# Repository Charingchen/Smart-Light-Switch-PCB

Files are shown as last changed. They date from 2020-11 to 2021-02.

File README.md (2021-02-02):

# Smart Light Switch PCB
This board is powered by Flyback converter, converting 120VAC to 5VDC to power the ESP32 microcontroller. The onboard temperture sensor and montion sensor would be used for smart home configrations 
## Flyback Converter Schematic
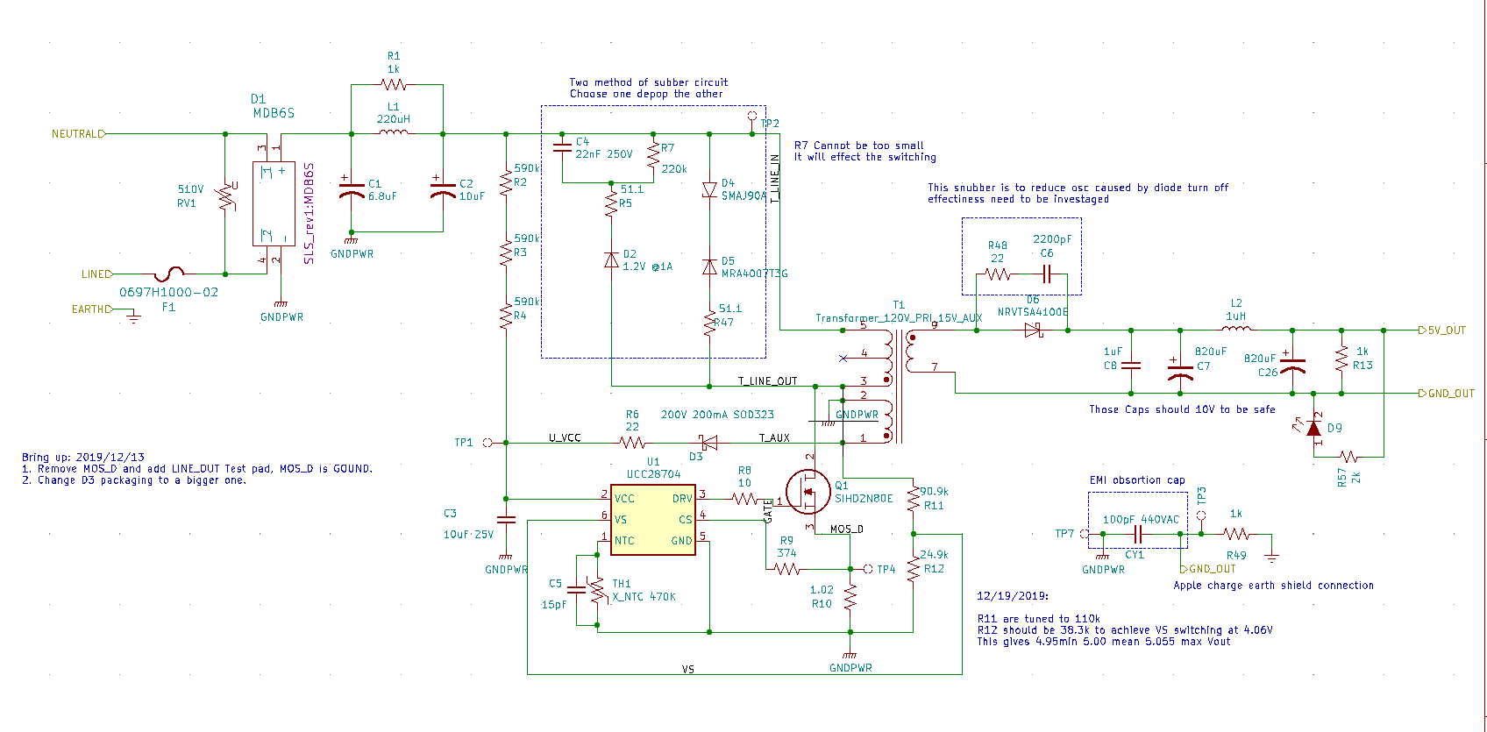
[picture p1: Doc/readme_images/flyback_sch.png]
sch

## PCB
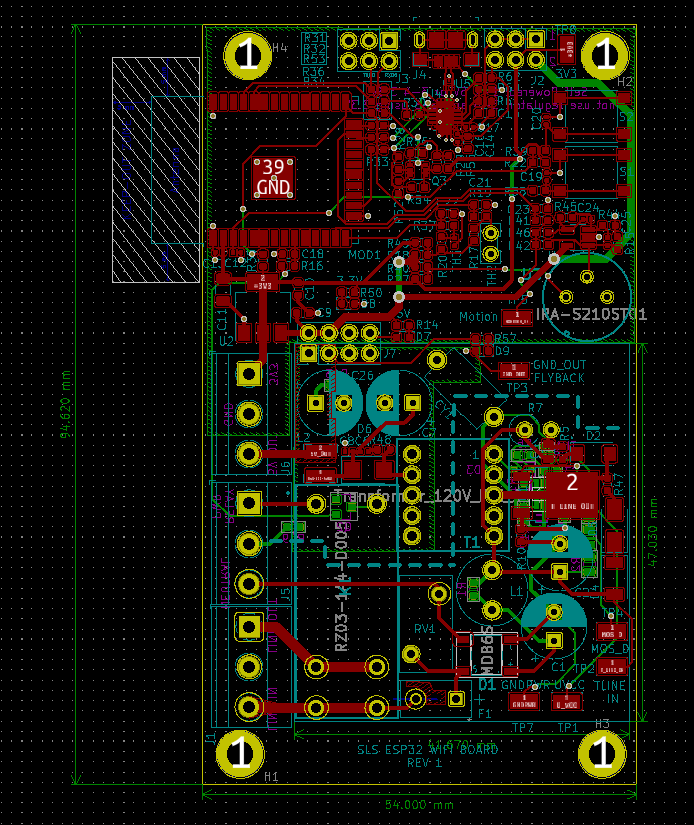
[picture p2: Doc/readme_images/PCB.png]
PCB

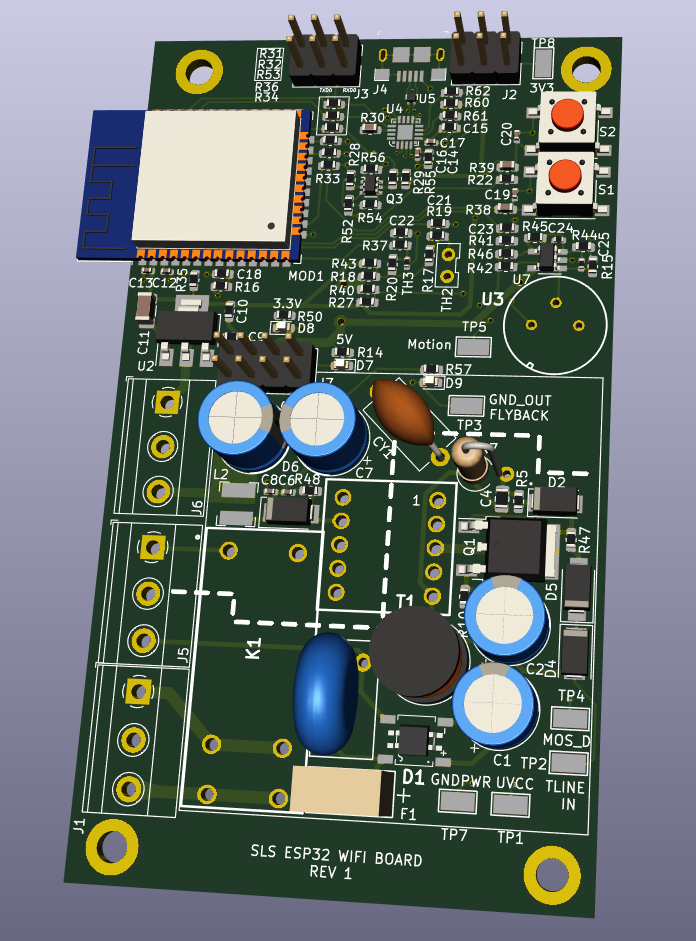
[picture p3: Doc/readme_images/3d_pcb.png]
3d


## Rev 1 Flyback Assemble PCB
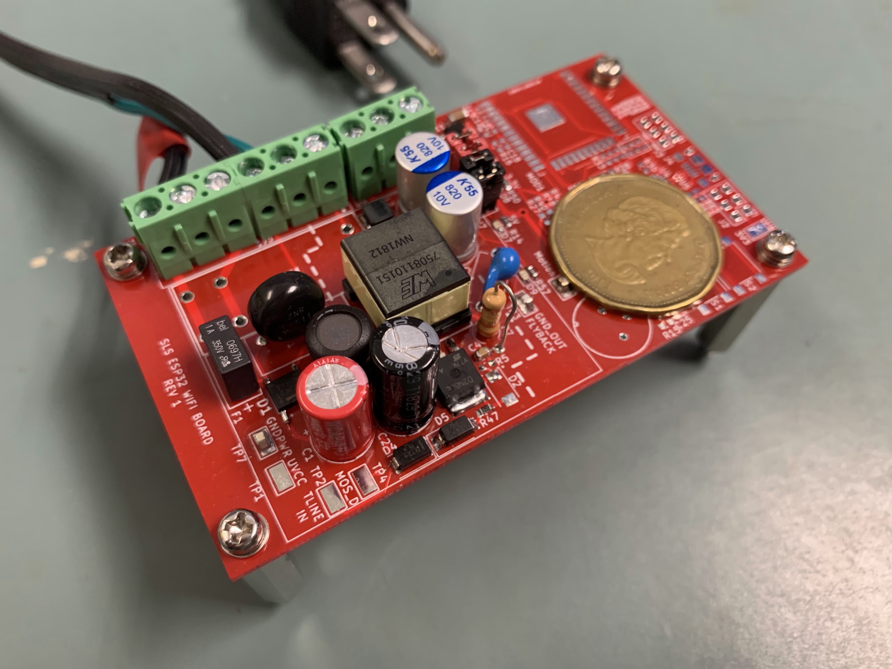
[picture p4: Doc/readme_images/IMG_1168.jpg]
product


## Kicad
This project uses Kicad to draw schematic and PCB
You can download [Kicad](https://kicad.org/) and open SLS_rev1.pro

### Digikey Library
I used digikey kicad Library to place most of the components:
https://www.digikey.ca/en/resources/design-tools/kicad

## Blog Post

I wrote some blog post talk about flyback controller, you can check them out below:

 <a target="_blank" href="https://github-readme-medium-recent-article.vercel.app/medium/@charingchen/2">Recent Article 2
 
 <a target="_blank" href="https://github-readme-medium-recent-article.vercel.app/medium/@charingchen/3">Recent Article 3

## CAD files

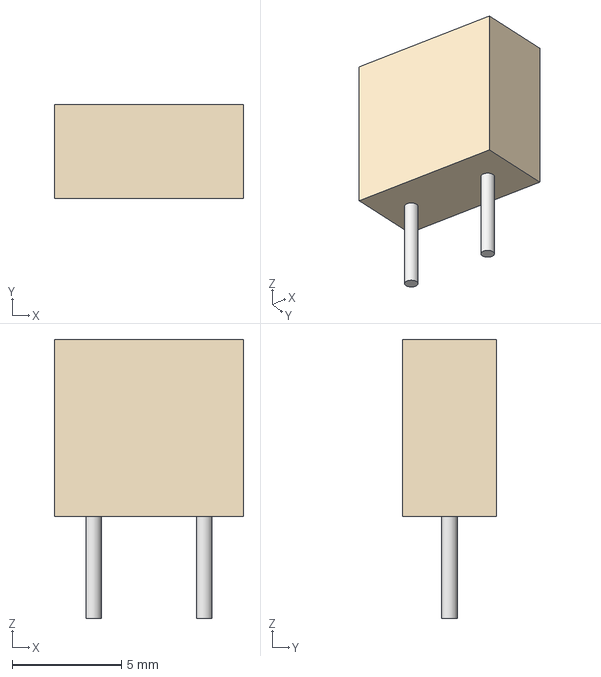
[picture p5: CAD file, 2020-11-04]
external lib/2019-09-20_19-07-09/STEP/0697.step
8.66 x 4.29 x 12.8 mm

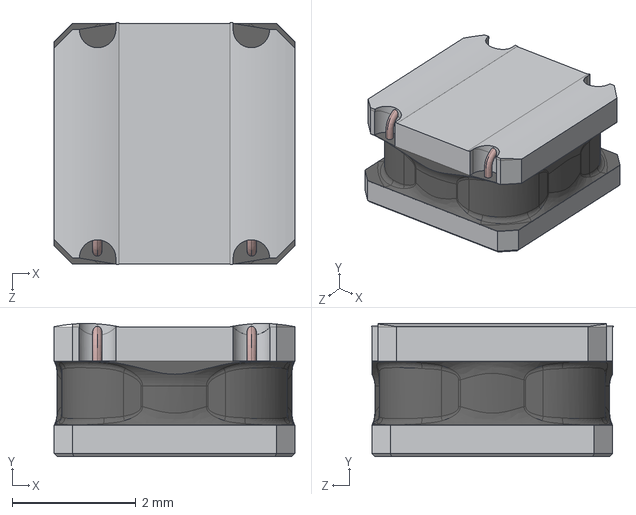
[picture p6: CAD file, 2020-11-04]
external lib/PCB footprint 3D/SRN4026 Series.stp
3.90 x 2.15 x 3.91 mm

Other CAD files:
external lib/UL_0697H100002/2019-10-03_00-56-25/STEP/0697.step

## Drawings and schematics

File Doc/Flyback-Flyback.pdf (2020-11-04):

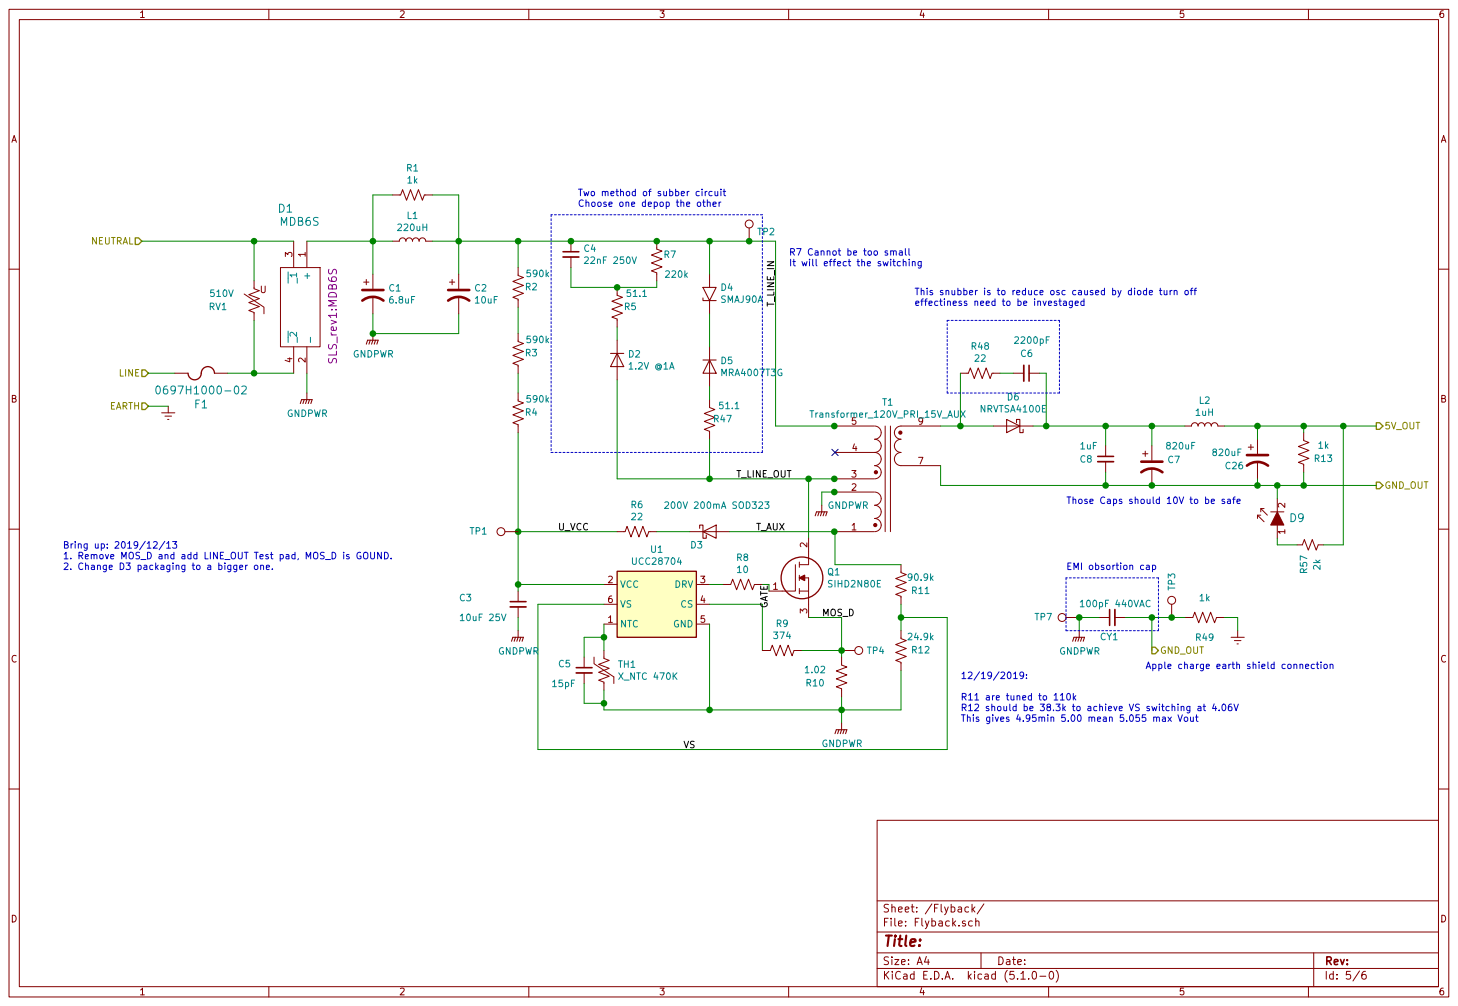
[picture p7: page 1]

Two method of subber circuit Choose one depop the other

R7 Cannot be too small It will effect the switching
51.1 D4 SMAJ90A

This snubber is to reduce osc caused by diode turn off

Those Caps should 10V to be safe

Bring up: 2019/12/13
1. Remove MOS_D and add LINE_OUT Test pad, MOS_D is GOUND.

Apple charge earth shield connection

This gives 4.95min 5.00 mean 5.055 max Vout

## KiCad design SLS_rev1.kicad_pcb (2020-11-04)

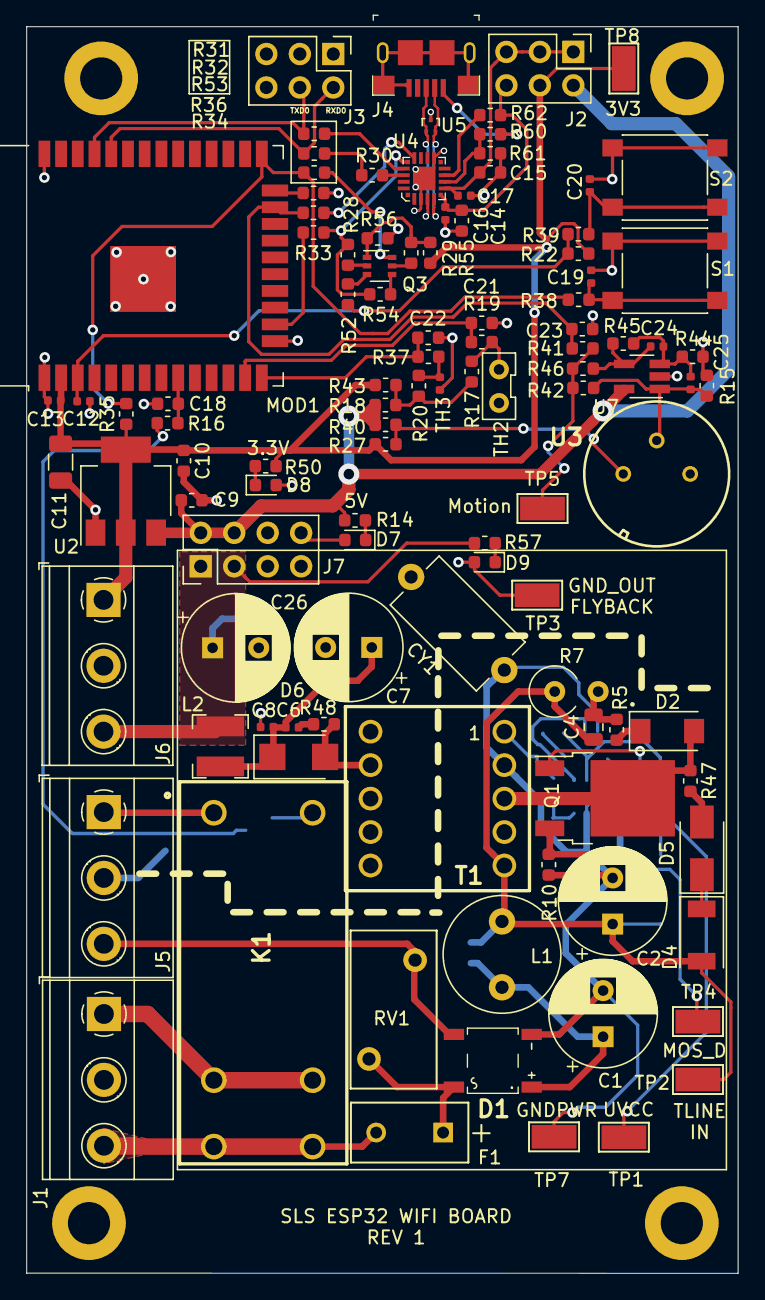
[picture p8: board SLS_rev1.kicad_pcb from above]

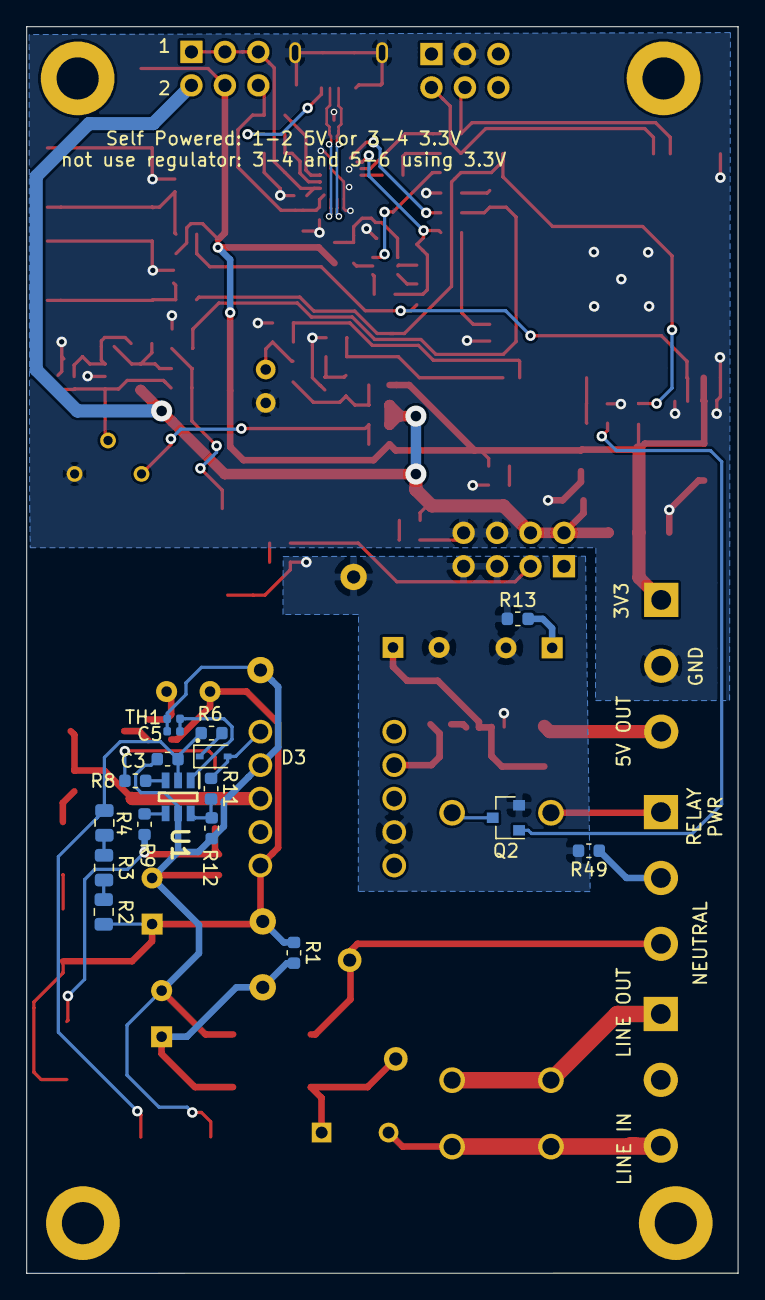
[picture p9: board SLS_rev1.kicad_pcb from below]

Board: 2 copper layers, 54.0 x 94.6 mm, 129 parts (17 on the bottom side), 76 nets.

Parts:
C1: 6.8uF; CP_Radial_D8.0mm_P3.50mm
C2: 10uF; CP_Radial_D8.0mm_P3.50mm
C3: 10uF 25V; C_0603_1608Metric
C4: 22nF 250V; R_0805_2012Metric
C5, C24, C25: 15pF; R_0402_1005Metric
C6: 2200pF; C_0402_1005Metric
C7, C26: 820uF; CP_Radial_D8.0mm_P3.50mm
C8, C12, C13: 1uF; C_0402_1005Metric
C9, C10, C14, C15, C18, C21, C22, C23: 4.7uF; R_0603_1608Metric
C11: 100uF 6.3V; C_1206_3216Metric
C16, C17: 0.1uF; C_0402_1005Metric
C19, C20: 1nF; C_0402_1005Metric
CY1: 100pF 440VAC; C_Disc_D9.0mm_W5.0mm_P10.00mm
D1: MDB6S
D2: 1.2V @1A; D_GF1
D3: 200V 200mA SOD323; D_SOD-323
D4: SMAJ90A
D5: MRA4007T3G; D_SMA
D6: NRVTSA4100E; D_SMA
D7, D8, D9: LTST-C190KGKT; LED_0603_1608Metric
F1: 0697H1000-02
H1, H2, H3, H4: MountingHole; MountingHole_3.2mm_M3_DIN965_Pad
J1, J5, J6: Phoenix_3pos_5mm; TerminalBlock_Phoenix_MKDS-1,5-3_1x03_P5.00mm_Horizontal
J2, J3: Conn_02x03_Odd_Even; PinHeader_2x03_P2.54mm_Vertical
J4: 10118193-0001LF; USB_Micro_B_Female_10118193-0001LF
J7: Conn_02x04_Odd_Even; PinHeader_2x04_P2.54mm_Vertical
K1: RZ03-1A4-D005
L1: 220uH; L_Radial_D8.7mm_P5.00mm_Fastron_07HCP
L2: 1uH; L_Bourns-SRN4018
MOD1: ESP32-WROOM-32
Q1: SIHD2N80E; TO-252-2
Q2: SSM3K257R; SOT-23
Q3: MBT3904DW1T1G; SOT-363_SC-70-6
R1, R13, R44, R49, R62: 1k; R_0603_1608Metric
R2, R3, R4: 590k; R_0805_2012Metric
R5, R47: 51.1; R_0603_1608Metric
R6, R48: 21.5; R_0603_1608Metric
R7: 220k; R_Axial_DIN0309_L9.0mm_D3.9mm_P2.54mm_Vertical
R8: 10; R_0603_1608Metric
R9: 374; R_0603_1608Metric
R10: 1.02; R_0603_1608Metric
R11: 90.9k; R_0603_1608Metric
R12: 24.9k; R_0603_1608Metric
R14, R50, R57: 2k; R_0603_1608Metric
R15: 43k; R_0603_1608Metric
R16, R18, R19, R27, R31, R32, R33, R34, R37, R40, R41, R42, R43, R46, R52, R53, R54, R55, R56: R_0ohm; R_0603_1608Metric
R17, R28, R29, R35, R36: 10k; R_0603_1608Metric
R20: 100k; R_0603_1608Metric
R22: 12k; R_0603_1608Metric
R30, R38, R39: 470; C_0603_1608Metric
R45: 75k; R_0603_1608Metric
R60: 22.1K; R_0603_1608Metric
R61: 47K; R_0603_1608Metric
RV1: 510V; ERZ10D511
S1, S2: PTS645SM43SMTR92_LFS; SW_SPST_PTS645
T1: Transformer_120V_PRI_15V_AUX; 7508110151
TH1: X_NTC 470K; R_0402_1005Metric
TH2: 10k NTC; NTCLE100E3103ht1
TH3: 100k NTC; R_0402_1005Metric
TP1, TP2, TP3, TP4, TP5, TP7, TP8: Keystone5015; TestPoint_Keystone_5015_Micro-Minature
U1: UCC28704; UCC28704DBVR-1
U2: AP2114H-3_3TRG1; SOT-223-3_TabPin2
U3: IRA-S210ST01; VZ-STANDARD
U4: CP2102N-A02-GQFN20R; QFN-20-1EP_3x3mm
U5: TPD2EUSB30; Texas_DRT-3
U7: LMV321; SOT-23-5_HandSoldering

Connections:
+3V3: C10.1, C11.1, C13.1, J2.4, J6.1, MOD1.2, R22.1, R27.1, R35.1, R43.1, R50.1, R55.1, TP8.1, U2.2
+5V: C9.1, J2.2, J7.2, J7.4, R14.1, R18.1, R40.1, U2.3, U7.5
/Flyback/5V_OUT: C26.1, J6.3, J7.1, J7.3, L2.2, R13.2, R57.2
/Flyback/GATE: Q1.1, R8.1
/Flyback/GND_OUT: C7.2, C8.2, C26.2, CY1.2, D9.2, J7.5, J7.7, Q2.2, R13.1, R49.2, T1.7, TP3.1
/Flyback/MOS_D: Q1.3, R9.1, R10.2, TP4.1
/Flyback/T_AUX: D3.2, R11.2, T1.1
/Flyback/T_LINE_IN: C2.1, C4.1, D4.2, L1.2, R1.1, R2.2, R7.1, T1.5, TP2.1
/Flyback/T_LINE_OUT: D2.A, Q1.2, R47.1, T1.3
/Flyback/U_VCC: C3.1, R4.1, R6.2, TP1.1, U1.2
/Flyback/VS: R11.1, R12.2, U1.6
/LINE_IN: F1.2, J1.3, K1.3, K1.4
/LINE_OUT: J1.1, K1.2, K1.5
/NEUTRAL: D1.3, J5.3, RV1.2
/Relay_switch/CONTROL: Q2.1, R16.2
/Relay_switch/VCC: J5.1, K1.1
/esp32 controlller/ADC1_CH0: C21.2, MOD1.13, R19.1
/esp32 controlller/ADC1_CH3: C22.2, MOD1.14, R37.1
/esp32 controlller/ADC1_CH6: C23.2, MOD1.23, R34.1, R41.1
/esp32 controlller/CTS: R34.2, U4.15
/esp32 controlller/DTR: Q3.1, R29.2, R55.2, R56.1
/esp32 controlller/EN: C12.1, MOD1.3, R22.2, R39.1, R52.2
/esp32 controlller/IO0: MOD1.25, R35.2, R38.1, R53.1
/esp32 controlller/IO2: MOD1.24, R36.1
/esp32 controlller/IO13: MOD1.16, R33.1
/esp32 controlller/IO33: C18.2, MOD1.9, R16.1
/esp32 controlller/MONTION_IN: R41.2, R42.2, R46.1, TP5.1
/esp32 controlller/RTS: R28.1, R33.2, R54.1, U4.16
/esp32 controlller/RXD: R31.2, U4.17
/esp32 controlller/RXD0: J3.2, MOD1.34, R32.1
/esp32 controlller/TEMP_IN_1: R17.2, R19.2, TH2.1
/esp32 controlller/TEMP_IN_2: R20.2, R37.2, TH3.1
/esp32 controlller/TXD: R30.1, R32.2
/esp32 controlller/TXD0: J3.4, MOD1.35, R31.1
/esp32 controlller/USB_D+: J4.3, U4.4, U5.1
/esp32 controlller/USB_D-: J4.2, U4.5, U5.2
/esp32 controlller/USB_VBUS: J4.1, R60.2
/esp32 controlller/USB_VDD: C14.2, C16.2, J2.6, R62.1, U4.6
/esp32 controlller/USB_VREGIN: C15.2, C17.2, J2.1, J2.3, J2.5, U4.7
Earth: J5.2, R49.1
GND: C9.2, C10.2, C11.2, C12.2, C13.2, C14.1, C15.1, C16.1, C17.1, C18.1, C19.2, C20.2, C21.1, C22.1, C23.1, D7.2, D8.2, J3.3, J4.5, J4.SH, J6.2, J7.6, J7.8, MOD1.1, MOD1.15, MOD1.38, MOD1.39, R15.2, R36.2, R44.2, R56.2, R61.2, S1.1, S1.2, S2.1, S2.2, TH2.2, TH3.2, U2.1, U3.3, U4.3, U4.12, U4.21, U5.3, U7.2
GNDPWR: C1.2, C2.2, C3.2, C5.2, CY1.1, D1.2, R10.1, R12.1, T1.2, TH1.2, TP7.1, U1.5
unnamed: C1.1, D1.1, L1.1, R1.2
unnamed: C4.2, R5.2, R7.2
unnamed: C5.1, TH1.1, U1.1
unnamed: C6.1, C7.1, C8.1, D6.1, L2.1
unnamed: C6.2, R48.1
unnamed: C19.1, R38.2, S1.3, S1.4
unnamed: C20.1, R39.2, S2.3, S2.4
unnamed: C24.1, R45.1, R46.2, U7.4
unnamed: C24.2, C25.2, R44.1, R45.2, U7.3
unnamed: C25.1, R15.1, R42.1, U3.2, U7.1
unnamed: D1.4, F1.1, RV1.1
unnamed: D2.K, R5.1
unnamed: D3.1, R6.1
unnamed: D4.1, D5.1
unnamed: D5.2, R47.2
unnamed: D6.2, R48.2, T1.9
unnamed: D7.1, R14.2
unnamed: D8.1, R50.2
unnamed: D9.1, R57.1
unnamed: K1.6, Q2.3
unnamed: Q3.2, R28.2
unnamed: Q3.3, R52.1
unnamed: Q3.4, R54.2
unnamed: Q3.5, R29.1
unnamed: Q3.6, R53.2
unnamed: R2.1, R3.2
unnamed: R3.1, R4.2
unnamed: R8.2, U1.3
unnamed: R9.2, U1.4
unnamed: R17.1, R18.2, R20.1, R43.2
unnamed: R27.2, R40.2, U3.1
unnamed: R30.2, U4.18
unnamed: R60.1, R61.1, U4.8
unnamed: R62.2, U4.9

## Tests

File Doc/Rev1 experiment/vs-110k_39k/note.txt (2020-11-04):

R12 change from 32k to39k due to output overvoltage and keep shutting off. Load with 32k setting would not change that behaviour.
with 39k, output voltage mean at 4.8V. with not subber circuit. it obsever a lot of overshoot noise.

12-19-2019: adding subber next to see

12-20-2019:
Over voltage shut off is due to no load condition. This flyback does not work well with no load at all. Needs to have some load to have switching works effieniently. 

5V measure along with high voltage measurement is not accurate. The switching noise will be added to 5V rail. Measuring only 5V will result a much more clean rail

VS voltage divider needs to be adjust to be exactly 5V. The combination of 110k and 37.4k should give 5.09V with min 5.04 and max 5.14. Keeping the current 110k and 39k as it is to reduce LDO heat loss.

Op-amp only connected to 5V rail. Might need to change that later

TVS require less parts(but more expensive) reduce voltage peak by 300V (700V down to 400V)

Based on instrument current and power display: this flyback hag ~69% effiencey.

Next step:

Try on LDO to see the turn on OV still happens or not.

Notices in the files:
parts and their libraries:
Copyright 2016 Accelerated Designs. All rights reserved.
